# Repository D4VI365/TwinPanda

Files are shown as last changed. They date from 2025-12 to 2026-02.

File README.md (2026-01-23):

# TwinPanda
 Custom Split Wireless Keyboard (nRF52840)
 Un progetto di tastiera meccanica split custom, progettata per essere compatta, ergonomica e completamente wireless grazie alla tecnologia Bluetooth.
 Caratteristiche Principali
 Cervello: Basata su Seeed Studio XIAO nRF52840, ideale per un basso consumo energetico e connettività Bluetooth integrata.
 Espansione I/O: Utilizzo di un chip MCP23017 (SSOP-28) per gestire la matrice dei tasti tramite protocollo $I^2C$.
 Layout Ergonomico: Layout split da 76 tasti ottimizzato per il comfort.
 Case Custom: Progettato in Fusion 360 per essere stampato in 3D con un top frame da 4.5 mm e inserti filettati M3 per la massima solidità.
 Gestione Batteria: Circuito di Battery Sense integrato per il monitoraggio in tempo reale della carica tramite partitore di tensione ($820k\Ohm / 2M\Ohm$).
 
Case:
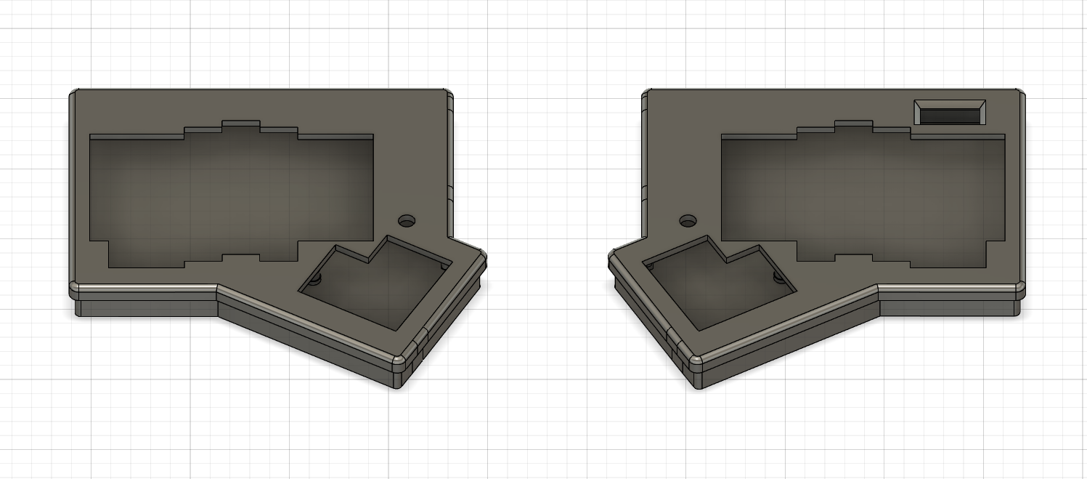
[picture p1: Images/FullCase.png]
FullCase

Full assembly:
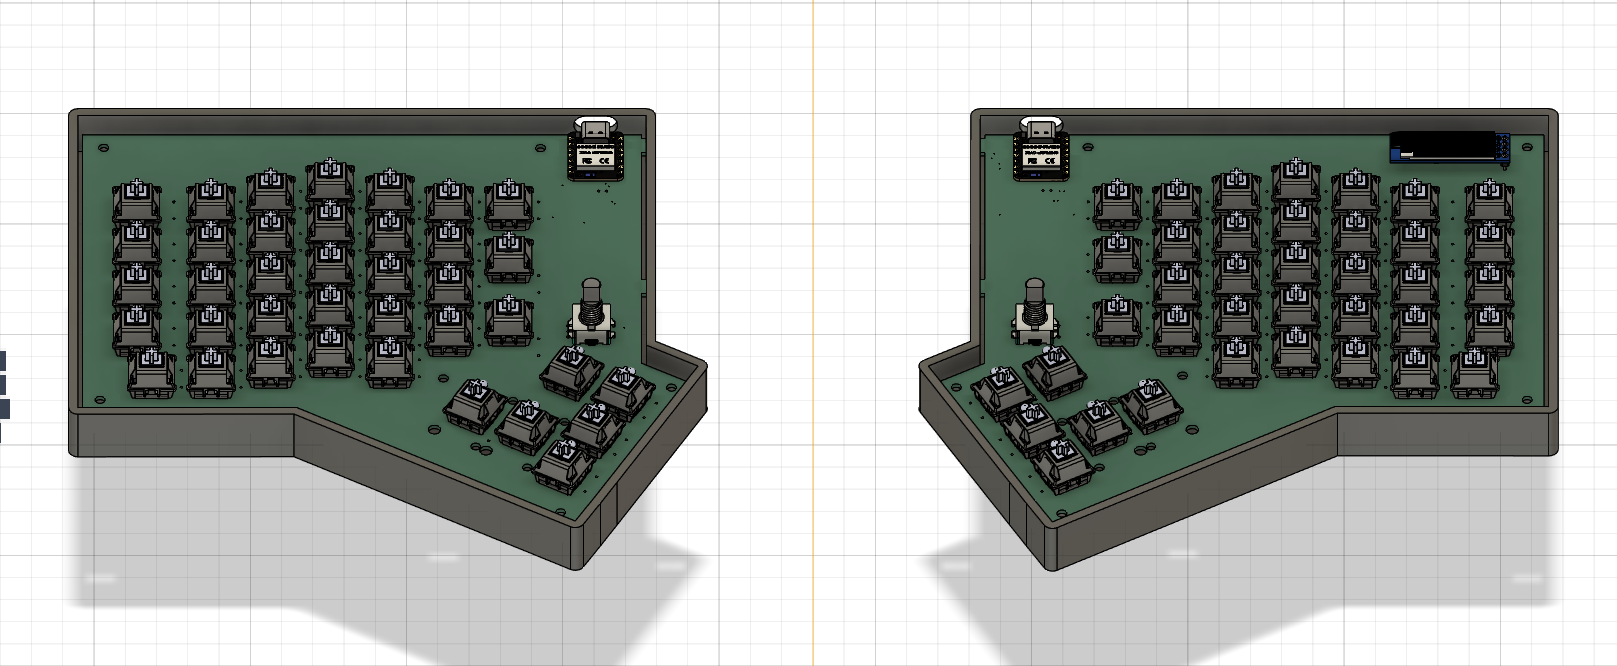
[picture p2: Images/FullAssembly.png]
FullAssembly


PCB Design:
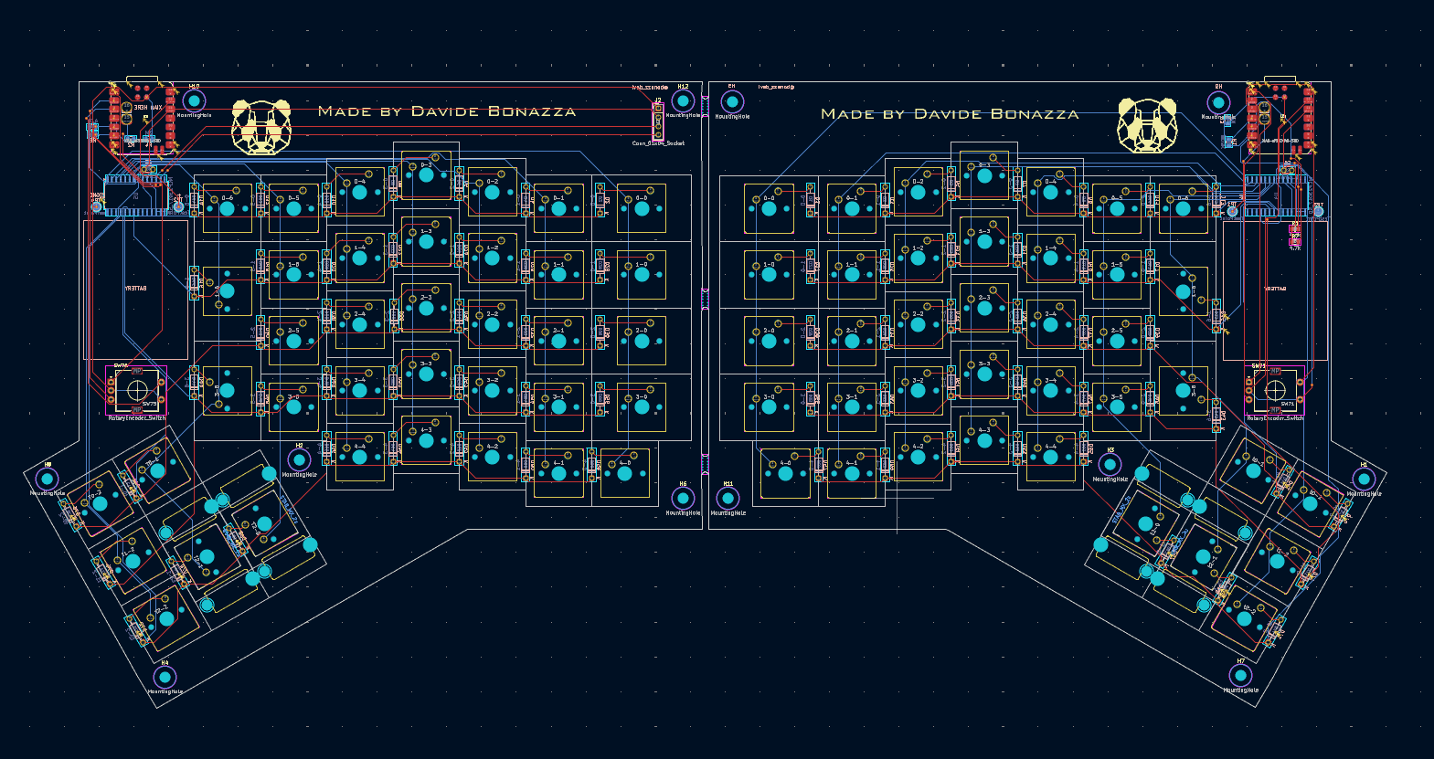
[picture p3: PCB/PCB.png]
PCB


Left Schematic:
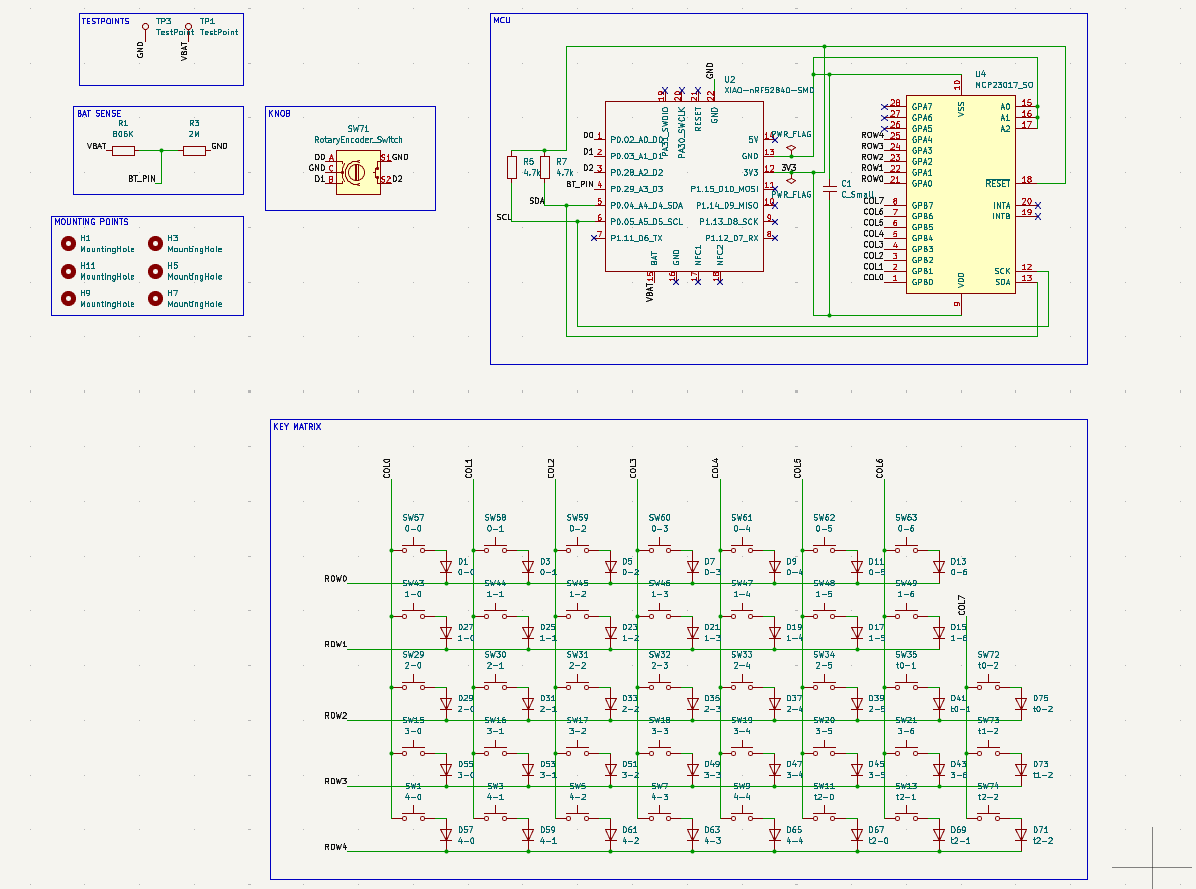
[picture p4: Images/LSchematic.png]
LSchematic


Right Schematic:
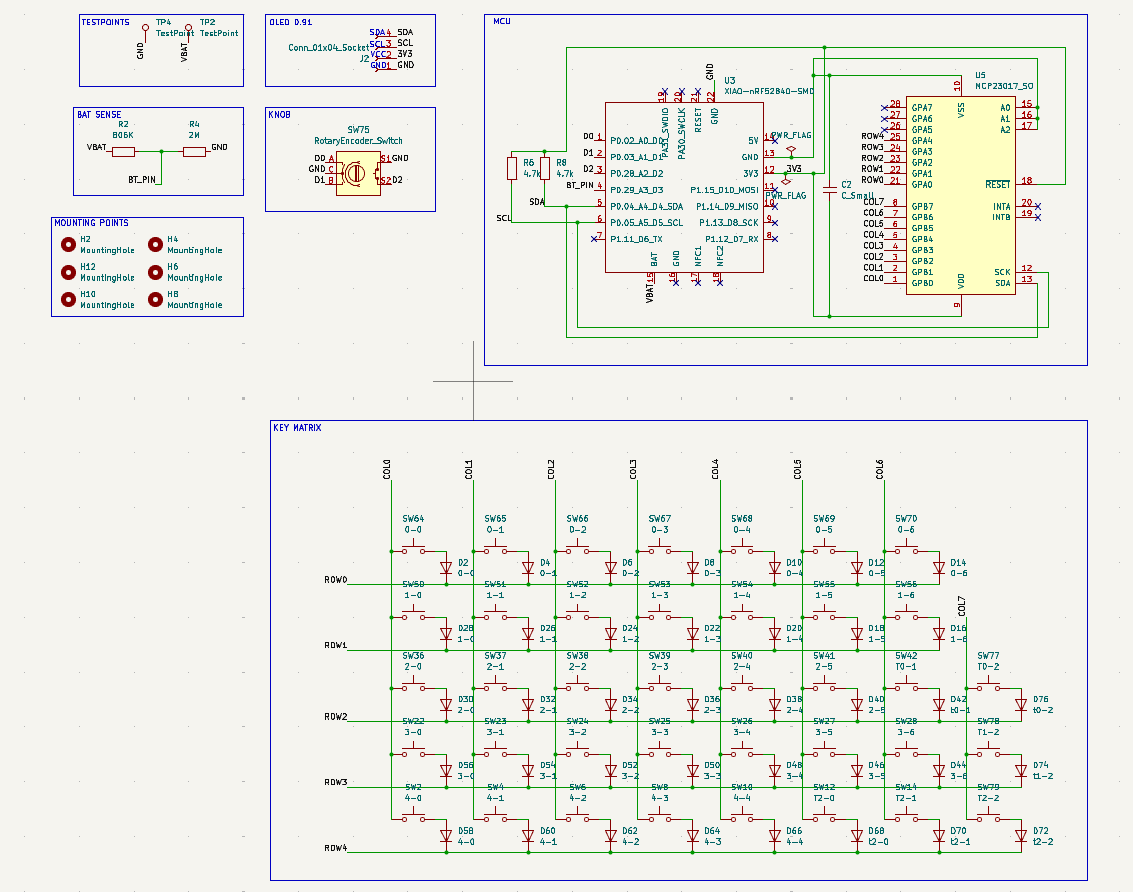
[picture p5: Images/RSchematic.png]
RSchematic


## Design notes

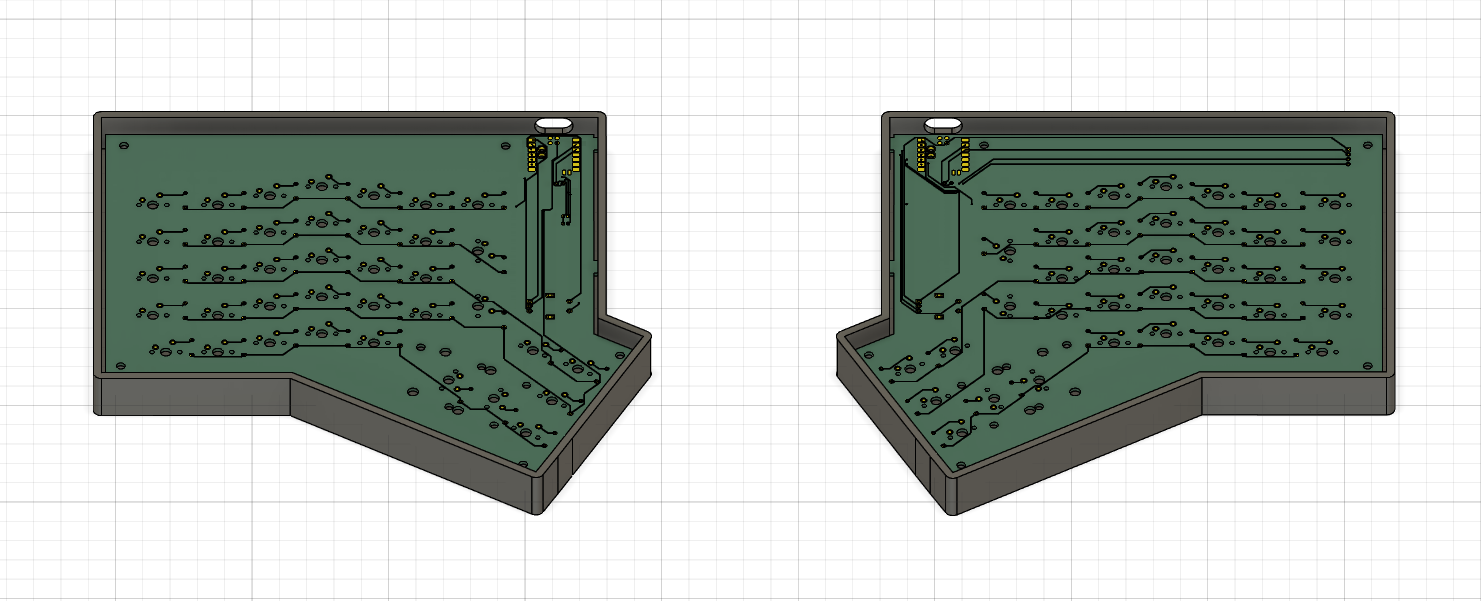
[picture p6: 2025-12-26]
Images/CasePCB.png

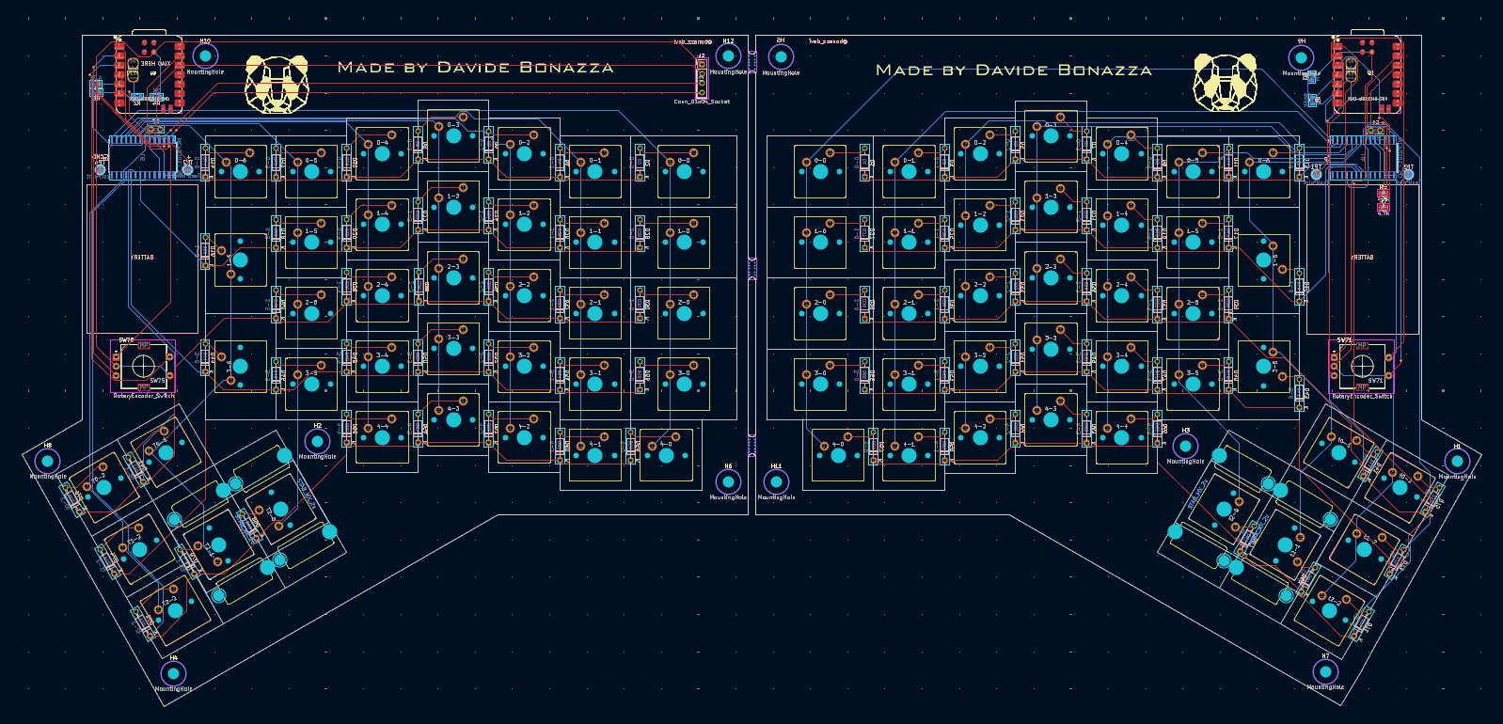
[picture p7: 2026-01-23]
Images/PCB.png

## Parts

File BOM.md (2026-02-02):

## Bill of Materials (BOM)

| Component | Qty | Total Price (USD) | Link | Supplier |
| :--- | :---: | :---: | :--- | :--- |
| **XIAO-nRF52840-SMD** | 2 | 25.03 | [Aliexpress](https://it.aliexpress.com/item/1005006593701624.html) | Aliexpress |
| **MCP23017-SMD** | 2 | 2.40 | [Aliexpress](https://it.aliexpress.com/item/1005004887918583.html) | Aliexpress |
| **Switches (76pcs)** | 76 | 6.50 | [Temu](https://www.temu.com/it-en/g-601105431766700.html) | Temu |
| **Diodes (1N4148)** | 76 | 1.15 | [Temu](https://www.temu.com/it-en/g-601102325033412.html) | Temu |
| **Rotary Encoder** | 2 | 4.20 | [Aliexpress](https://it.aliexpress.com/item/1005006128088045.html) | Aliexpress |
| **4.7Kohm Resistor** | 4 | 2.98 | [Aliexpress](https://it.aliexpress.com/item/1005007129626034.html) | Aliexpress |
| **2Mohm Resistor** | 2 | 3.03 | [Aliexpress](https://it.aliexpress.com/item/1005007129626034.html) | Aliexpress |
| **820Kohm Resistor** | 2 | 3.03 | [Aliexpress](https://it.aliexpress.com/item/1005007129626034.html) | Aliexpress |
| **0.91" OLED Screen** | 1 | 1.81 | [Temu](https://www.temu.com/it-en/g-601100552968759.html) | Temu |
| **2u Key Stabilizer** | 4 | 2.28 | [Temu](https://www.temu.com/it-en/g-606163043249487.html) | Temu |
| **1u Keycaps (60pcs)** | 60 | 17.80 | [Alibaba](https://www.alibaba.com/product-detail/1601240068637.html) | Alibaba |
| **1.5u Keycaps (12pcs)** | 12 | 5.90 | [Alibaba](https://www.alibaba.com/product-detail/1601240068637.html) | Alibaba |
| **2u Keycaps (4pcs)** | 4 | 2.46 | [Alibaba](https://www.alibaba.com/product-detail/1601240068637.html) | Alibaba |
| **M3 Heat-press inserts** | 12 | 1.78 | [Temu](https://www.temu.com/it-en/g-601099714384815.html) | Temu |
| **M3 Screws** | 12 | 1.96 | [Temu](https://www.temu.com/goods.html?goods_id=601101875380737) | Temu |
| **PCB** | 1 | 50.00 | - | JLCPCB |
| **Battery** | 2 | 6.20 | [Aliexpress](https://it.aliexpress.com/item/32856929220.html) | Aliexpress |
| **Capacitor** | 1 | 1.92 | [Aliexpress](https://it.aliexpress.com/item/1005006378388179.html) | Aliexpress |
| --- | --- | --- | --- | --- |
| **TOTAL** | | **140.43** | | |

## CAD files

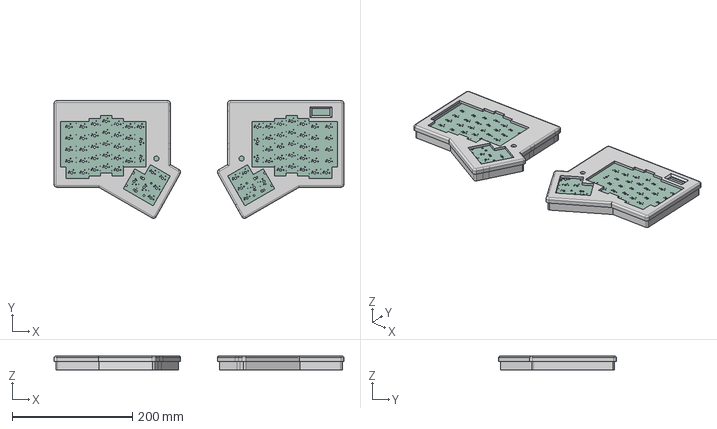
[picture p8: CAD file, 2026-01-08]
CAD/TwinPanda.step
482.5 x 195.9 x 23.5 mm

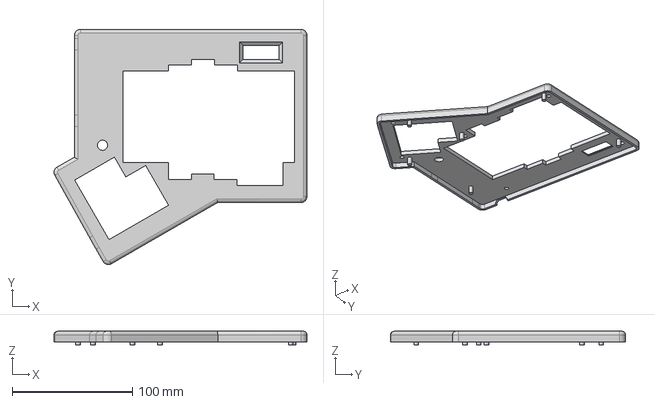
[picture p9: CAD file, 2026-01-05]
CAD/RTopCase.step
210.8 x 195.9 x 11.3 mm

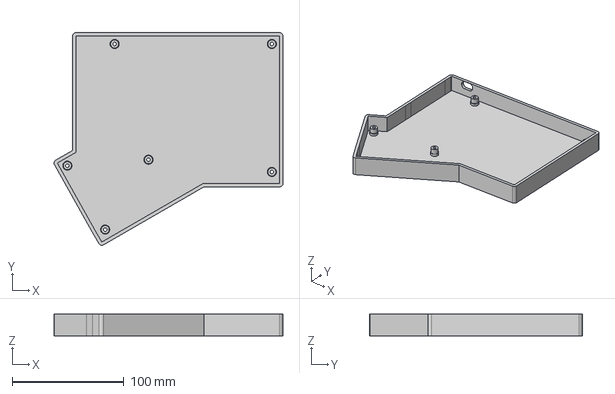
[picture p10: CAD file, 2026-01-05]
CAD/RBottomCase.step
204.5 x 189.9 x 19.3 mm

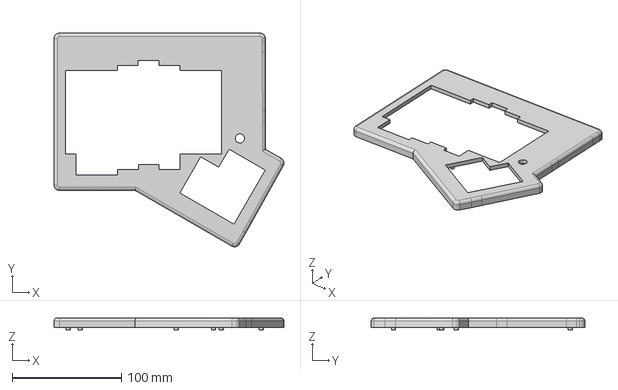
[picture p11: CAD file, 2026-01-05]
CAD/LTopCase.step
210.8 x 195.9 x 11.3 mm

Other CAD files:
CAD/LBottomCase.step
CAD/LBottomCase.stl
CAD/LTopCase.stl
CAD/RBottomCase.stl
CAD/RTopCase.stl
CAD/TwinPanda.f3z

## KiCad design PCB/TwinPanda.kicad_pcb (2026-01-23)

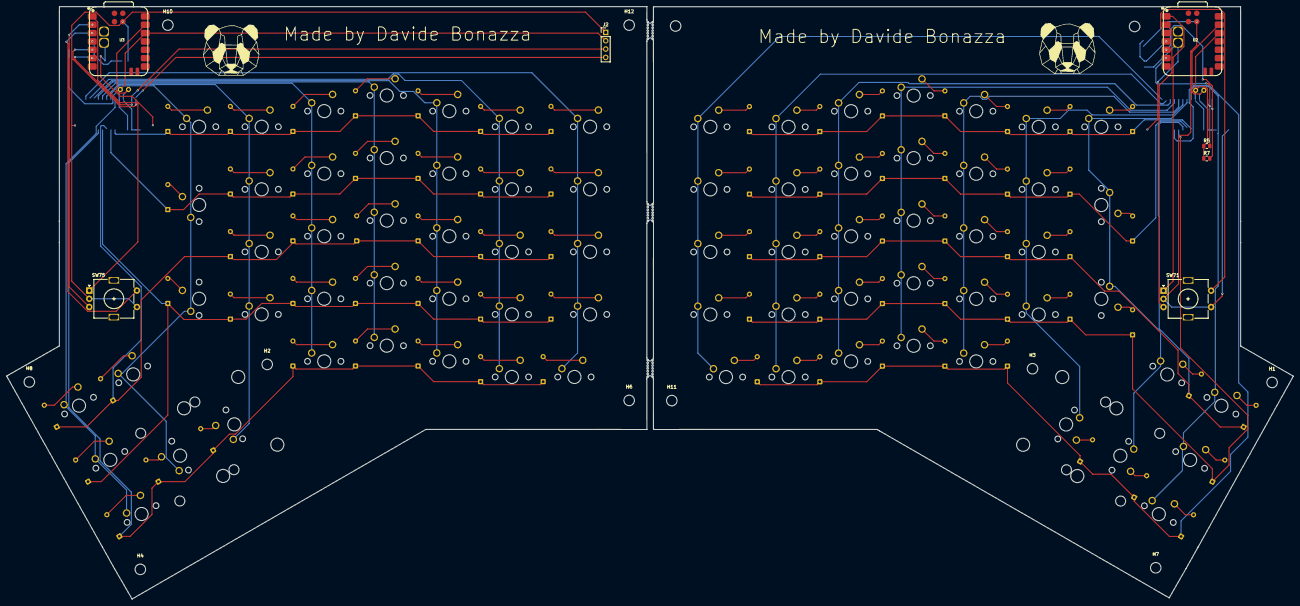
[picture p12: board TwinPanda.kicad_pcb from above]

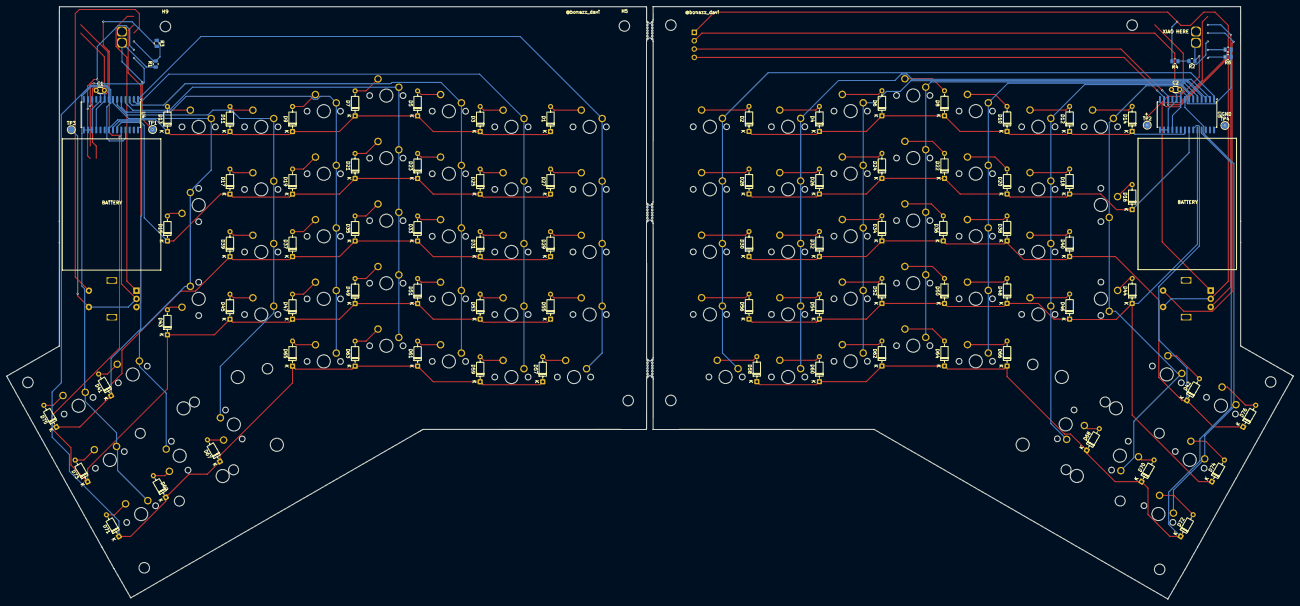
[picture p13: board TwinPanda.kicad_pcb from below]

Board: 2 copper layers, 391.8 x 180.4 mm, 188 parts (90 on the bottom side), 122 nets.

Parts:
BO0, BO1, BO2: MouseBites; MouseBite-Slot_2.0x4.5mm_outset_D0.5mm_P0.85mm_7h
C1, C2: C_Small; C_Disc_D3.0mm_W1.6mm_P2.50mm
D1, D2: 0-0; D_DO-35_SOD27_P7.62mm_Horizontal
D3, D4: 0-1; D_DO-35_SOD27_P7.62mm_Horizontal
D5, D6: 0-2; D_DO-35_SOD27_P7.62mm_Horizontal
D7, D8: 0-3; D_DO-35_SOD27_P7.62mm_Horizontal
D9, D10: 0-4; D_DO-35_SOD27_P7.62mm_Horizontal
D11, D12: 0-5; D_DO-35_SOD27_P7.62mm_Horizontal
D13, D14: 0-6; D_DO-35_SOD27_P7.62mm_Horizontal
D15, D16: 1-6; D_DO-35_SOD27_P7.62mm_Horizontal
D17, D18: 1-5; D_DO-35_SOD27_P7.62mm_Horizontal
D19, D20: 1-4; D_DO-35_SOD27_P7.62mm_Horizontal
D21, D22: 1-3; D_DO-35_SOD27_P7.62mm_Horizontal
D23, D24: 1-2; D_DO-35_SOD27_P7.62mm_Horizontal
D25, D26: 1-1; D_DO-35_SOD27_P7.62mm_Horizontal
D27, D28: 1-0; D_DO-35_SOD27_P7.62mm_Horizontal
D29, D30: 2-0; D_DO-35_SOD27_P7.62mm_Horizontal
D31, D32: 2-1; D_DO-35_SOD27_P7.62mm_Horizontal
D33, D34: 2-2; D_DO-35_SOD27_P7.62mm_Horizontal
D35, D36: 2-3; D_DO-35_SOD27_P7.62mm_Horizontal
D37, D38: 2-4; D_DO-35_SOD27_P7.62mm_Horizontal
D39, D40: 2-5; D_DO-35_SOD27_P7.62mm_Horizontal
D41, D42: t0-1; D_DO-35_SOD27_P7.62mm_Horizontal
D43, D44: 3-6; D_DO-35_SOD27_P7.62mm_Horizontal
D45, D46: 3-5; D_DO-35_SOD27_P7.62mm_Horizontal
D47, D48: 3-4; D_DO-35_SOD27_P7.62mm_Horizontal
D49, D50: 3-3; D_DO-35_SOD27_P7.62mm_Horizontal
D51, D52: 3-2; D_DO-35_SOD27_P7.62mm_Horizontal
D53, D54: 3-1; D_DO-35_SOD27_P7.62mm_Horizontal
D55, D56: 3-0; D_DO-35_SOD27_P7.62mm_Horizontal
D57, D58: 4-0; D_DO-35_SOD27_P7.62mm_Horizontal
D59, D60: 4-1; D_DO-35_SOD27_P7.62mm_Horizontal
D61, D62: 4-2; D_DO-35_SOD27_P7.62mm_Horizontal
D63, D64: 4-3; D_DO-35_SOD27_P7.62mm_Horizontal
D65, D66: 4-4; D_DO-35_SOD27_P7.62mm_Horizontal
D67, D68: t2-0; D_DO-35_SOD27_P7.62mm_Horizontal
D69, D70: t2-1; D_DO-35_SOD27_P7.62mm_Horizontal
D71, D72: t2-2; D_DO-35_SOD27_P7.62mm_Horizontal
D73, D74: t1-2; D_DO-35_SOD27_P7.62mm_Horizontal
D75, D76: t0-2; D_DO-35_SOD27_P7.62mm_Horizontal
H1, H2, H3, H4, H5, H6, H7, H8, H9, H10, H11, H12: MountingHole; MountingHole_3.2mm_M3
J2: Conn_01x04_Socket; PinHeader_1x04_P2.54mm_Vertical
R1, R2: 806K; R_0805_2012Metric
R3, R4: 2M; R_0805_2012Metric
R5, R6, R7, R8: 4.7k; R_0805_2012Metric
SW1, SW2: 4-0; SW_MX_1u
SW3, SW4: 4-1; SW_MX_1u
SW5, SW6: 4-2; SW_MX_1u
SW7, SW8: 4-3; SW_MX_1u
SW9, SW10: 4-4; SW_MX_1u
SW11: t2-0; SW_MX_1u
SW12: T2-0; SW_MX_1u
SW13: t2-1; SW_MX_1u
SW14: T2-1; SW_MX_1u
SW15, SW22: 3-0; SW_MX_1.5u
SW16, SW23: 3-1; SW_MX_1u
SW17, SW24: 3-2; SW_MX_1u
SW18, SW25: 3-3; SW_MX_1u
SW19, SW26: 3-4; SW_MX_1u
SW20, SW27: 3-5; SW_MX_1u
SW21, SW28: 3-6; SW_MX_1.5u
SW29, SW36: 2-0; SW_MX_1.5u
SW30, SW37: 2-1; SW_MX_1u
SW31, SW38: 2-2; SW_MX_1u
SW32, SW39: 2-3; SW_MX_1u
SW33, SW40: 2-4; SW_MX_1u
SW34, SW41: 2-5; SW_MX_1u
SW35: t0-1; SW_MX_1u
SW42: T0-1; SW_MX_1u
SW43, SW50: 1-0; SW_MX_1.5u
SW44, SW51: 1-1; SW_MX_1u
SW45, SW52: 1-2; SW_MX_1u
SW46, SW53: 1-3; SW_MX_1u
SW47, SW54: 1-4; SW_MX_1u
SW48, SW55: 1-5; SW_MX_1u
SW49, SW56: 1-6; SW_MX_1.5u
SW57, SW64: 0-0; SW_MX_1.5u
SW58, SW65: 0-1; SW_MX_1u
SW59, SW66: 0-2; SW_MX_1u
SW60, SW67: 0-3; SW_MX_1u
SW61, SW68: 0-4; SW_MX_1u
SW62, SW69: 0-5; SW_MX_1u
SW63, SW70: 0-6; SW_MX_1u
SW71, SW75: RotaryEncoder_Switch; RotaryEncoder_Alps_EC11E-Switch_Vertical_H20mm
SW72: t0-2; SW_MX_1u
SW73: t1-2; SW_MX_1u
SW74: t2-2; SW_MX_1u
SW77: T0-2; SW_MX_1u
SW78: T1-2; SW_MX_1u
SW79: T2-2; SW_MX_1u
TP1, TP2, TP3, TP4: TestPoint; TestPoint_Pad_D2.0mm
U2, U3: XIAO-nRF52840-SMD; modified-XIAO-nRF52840-SMD
U4, U5: MCP23017_SO; SOIC-28W_7.5x17.9mm_P1.27mm

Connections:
/Left/3V3: C1.2, R5.1, R7.1, U2.12 (3V3), U4.9 (VDD), U4.18 (~RESET)
/Left/BT_PIN: R1.2, R3.1, U2.4 (P0.29_A3_D3)
/Left/COL0: SW1.1, SW15.1, SW29.1, SW43.1, SW57.1, U4.1 (GPB0)
/Left/COL1: SW3.1, SW16.1, SW30.1, SW44.1, SW58.1, U4.2 (GPB1)
/Left/COL2: SW5.1, SW17.1, SW31.1, SW45.1, SW59.1, U4.3 (GPB2)
/Left/COL3: SW7.1, SW18.1, SW32.1, SW46.1, SW60.1, U4.4 (GPB3)
/Left/COL4: SW9.1, SW19.1, SW33.1, SW47.1, SW61.1, U4.5 (GPB4)
/Left/COL5: SW11.1, SW20.1, SW34.1, SW48.1, SW62.1, U4.6 (GPB5)
/Left/COL6: SW13.1, SW21.1, SW35.1, SW49.1, SW63.1, U4.7 (GPB6)
/Left/COL7: SW72.1, SW73.1, SW74.1, U4.8 (GPB7)
/Left/D0: SW71.A, U2.1 (P0.02_A0_D0)
/Left/D1: SW71.B, U2.2 (P0.03_A1_D1)
/Left/D2: SW71.S2, U2.3 (P0.28_A2_D2)
/Left/GND: R3.2, SW71.C, SW71.S1, TP3.1, U2.22 (GND)
/Left/ROW0: D1.1 (K), D3.1 (K), D5.1 (K), D7.1 (K), D9.1 (K), D11.1 (K), D13.1 (K), U4.21 (GPA0)
/Left/ROW1: D15.1 (K), D17.1 (K), D19.1 (K), D21.1 (K), D23.1 (K), D25.1 (K), D27.1 (K), U4.22 (GPA1)
/Left/ROW2: D29.1 (K), D31.1 (K), D33.1 (K), D35.1 (K), D37.1 (K), D39.1 (K), D41.1 (K), D75.1 (K), U4.23 (GPA2)
/Left/ROW3: D43.1 (K), D45.1 (K), D47.1 (K), D49.1 (K), D51.1 (K), D53.1 (K), D55.1 (K), D73.1 (K), U4.24 (GPA3)
/Left/ROW4: D57.1 (K), D59.1 (K), D61.1 (K), D63.1 (K), D65.1 (K), D67.1 (K), D69.1 (K), D71.1 (K), U4.25 (GPA4)
/Left/SCL: R5.2, U2.6 (P0.05_A5_D5_SCL), U4.12 (SCK)
/Left/SDA: R7.2, U2.5 (P0.04_A4_D4_SDA), U4.13 (SDA)
/Left/VBAT: R1.1, TP1.1, U2.15 (BAT)
/Right/3V3: C2.2, J2.2, R6.1, R8.1, U3.12 (3V3), U5.9 (VDD), U5.18 (~RESET)
/Right/BT_PIN: R2.2, R4.1, U3.4 (P0.29_A3_D3)
/Right/COL0: SW2.1, SW22.1, SW36.1, SW50.1, SW64.1, U5.1 (GPB0)
/Right/COL1: SW4.1, SW23.1, SW37.1, SW51.1, SW65.1, U5.2 (GPB1)
/Right/COL2: SW6.1, SW24.1, SW38.1, SW52.1, SW66.1, U5.3 (GPB2)
/Right/COL3: SW8.1, SW25.1, SW39.1, SW53.1, SW67.1, U5.4 (GPB3)
/Right/COL4: SW10.1, SW26.1, SW40.1, SW54.1, SW68.1, U5.5 (GPB4)
/Right/COL5: SW12.1, SW27.1, SW41.1, SW55.1, SW69.1, U5.6 (GPB5)
/Right/COL6: SW14.1, SW28.1, SW42.1, SW56.1, SW70.1, U5.7 (GPB6)
/Right/COL7: SW77.1, SW78.1, SW79.1, U5.8 (GPB7)
/Right/D0: SW75.A, U3.1 (P0.02_A0_D0)
/Right/D1: SW75.B, U3.2 (P0.03_A1_D1)
/Right/D2: SW75.S2, U3.3 (P0.28_A2_D2)
/Right/GND: J2.1, R4.2, SW75.C, SW75.S1, TP4.1, U3.22 (GND)
/Right/ROW0: D2.1 (K), D4.1 (K), D6.1 (K), D8.1 (K), D10.1 (K), D12.1 (K), D14.1 (K), U5.21 (GPA0)
/Right/ROW1: D16.1 (K), D18.1 (K), D20.1 (K), D22.1 (K), D24.1 (K), D26.1 (K), D28.1 (K), U5.22 (GPA1)
/Right/ROW2: D30.1 (K), D32.1 (K), D34.1 (K), D36.1 (K), D38.1 (K), D40.1 (K), D42.1 (K), D76.1 (K), U5.23 (GPA2)
/Right/ROW3: D44.1 (K), D46.1 (K), D48.1 (K), D50.1 (K), D52.1 (K), D54.1 (K), D56.1 (K), D74.1 (K), U5.24 (GPA3)
/Right/ROW4: D58.1 (K), D60.1 (K), D62.1 (K), D64.1 (K), D66.1 (K), D68.1 (K), D70.1 (K), D72.1 (K), U5.25 (GPA4)
/Right/SCL: J2.3, R6.2, U3.6 (P0.05_A5_D5_SCL), U5.12 (SCK)
/Right/SDA: J2.4, R8.2, U3.5 (P0.04_A4_D4_SDA), U5.13 (SDA)
/Right/VBAT: R2.1, TP2.1, U3.15 (BAT)
unnamed: D1.2 (A), SW57.2
unnamed: D2.2 (A), SW64.2
unnamed: D3.2 (A), SW58.2
unnamed: D4.2 (A), SW65.2
unnamed: D5.2 (A), SW59.2
unnamed: D6.2 (A), SW66.2
unnamed: D7.2 (A), SW60.2
unnamed: D8.2 (A), SW67.2
unnamed: D9.2 (A), SW61.2
unnamed: D10.2 (A), SW68.2
unnamed: D11.2 (A), SW62.2
unnamed: D12.2 (A), SW69.2
unnamed: D13.2 (A), SW63.2
unnamed: D14.2 (A), SW70.2
unnamed: D15.2 (A), SW49.2
unnamed: D16.2 (A), SW56.2
unnamed: D17.2 (A), SW48.2
unnamed: D18.2 (A), SW55.2
unnamed: D19.2 (A), SW47.2
unnamed: D20.2 (A), SW54.2
unnamed: D21.2 (A), SW46.2
unnamed: D22.2 (A), SW53.2
unnamed: D23.2 (A), SW45.2
unnamed: D24.2 (A), SW52.2
unnamed: D25.2 (A), SW44.2
unnamed: D26.2 (A), SW51.2
unnamed: D27.2 (A), SW43.2
unnamed: D28.2 (A), SW50.2
unnamed: D29.2 (A), SW29.2
unnamed: D30.2 (A), SW36.2
unnamed: D31.2 (A), SW30.2
unnamed: D32.2 (A), SW37.2
unnamed: D33.2 (A), SW31.2
unnamed: D34.2 (A), SW38.2
unnamed: D35.2 (A), SW32.2
unnamed: D36.2 (A), SW39.2
unnamed: D37.2 (A), SW33.2
unnamed: D38.2 (A), SW40.2
unnamed: D39.2 (A), SW34.2
unnamed: D40.2 (A), SW41.2
unnamed: D41.2 (A), SW35.2
unnamed: D42.2 (A), SW42.2
unnamed: D43.2 (A), SW21.2
unnamed: D44.2 (A), SW28.2
unnamed: D45.2 (A), SW20.2
unnamed: D46.2 (A), SW27.2
unnamed: D47.2 (A), SW19.2
unnamed: D48.2 (A), SW26.2
unnamed: D49.2 (A), SW18.2
unnamed: D50.2 (A), SW25.2
unnamed: D51.2 (A), SW17.2
unnamed: D52.2 (A), SW24.2
unnamed: D53.2 (A), SW16.2
unnamed: D54.2 (A), SW23.2
unnamed: D55.2 (A), SW15.2
unnamed: D56.2 (A), SW22.2
unnamed: D57.2 (A), SW1.2
unnamed: D58.2 (A), SW2.2
unnamed: D59.2 (A), SW3.2
unnamed: D60.2 (A), SW4.2
unnamed: D61.2 (A), SW5.2
unnamed: D62.2 (A), SW6.2
unnamed: D63.2 (A), SW7.2
unnamed: D64.2 (A), SW8.2
unnamed: D65.2 (A), SW9.2
unnamed: D66.2 (A), SW10.2
unnamed: D67.2 (A), SW11.2
unnamed: D68.2 (A), SW12.2
unnamed: D69.2 (A), SW13.2
unnamed: D70.2 (A), SW14.2
unnamed: D71.2 (A), SW74.2
unnamed: D72.2 (A), SW79.2
unnamed: D73.2 (A), SW73.2
unnamed: D74.2 (A), SW78.2
unnamed: D75.2 (A), SW72.2
unnamed: D76.2 (A), SW77.2
unnamed: C1.1, U2.13 (GND), U4.10 (VSS), U4.15 (A0), U4.16 (A1), U4.17 (A2)
unnamed: C2.1, U3.13 (GND), U5.10 (VSS), U5.15 (A0), U5.16 (A1), U5.17 (A2)

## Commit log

2025-12-26 Added the files
    [BOM.csv]
2026-01-20 Add assembly and PCB schematic images
    Added FullAssembly.png to Images and LSchematic.png, RSchematic.png, and PCB.png to PCB directory for documentation and reference purposes.
2026-01-23 Update BOM, PCB layout, and assembly images
    Updated BOM.csv with new suppliers, lower prices, and alternative links for several components. Modified the PCB layout (TwinPanda.kicad_pcb) with significant changes to component and mounting hole p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
    [BOM.csv, TwinPanda.kicad_pcb]
2026-01-31 Update BOM with new prices, suppliers, and links
    Updated the Bill of Materials to reflect new prices, suppliers, and product links for multiple components. Some quantities and sources have changed, and total price has been recalculated. Added empty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
    [BOM.csv]
2026-01-31 Update BOM component prices
    Adjusted prices for several components in BOM.csv, including Switches, Diodes, Rotary Encoder, OLED screen, key stabilizer, M3 Heat-press insert, and M3 Screws. Updated the total price to reflect the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
    [BOM.csv]
2026-02-02 Update BOM currency label to USD
    Changed the 'Total price' column header in BOM.csv from an invalid character to 'Total price USD' for clarity.
    [BOM.csv]
2026-02-02 Simplify and update BOM component links
    Shortened and standardized URLs for several components in BOM.csv to remove tracking parameters and improve readability. Also updated the total price row and made minor formatting adjustments.
    [BOM.csv]
2026-02-02 Remove BOM.csv and move build.yaml to Firmware/
    Deleted the BOM.csv file and relocated build.yaml to the Firmware directory. This cleans up the project structure and organizes build configuration files.
    [BOM.csv]
2026-02-16 Add TwinPanda.f3z CAD model
    Add a new Fusion 360 archive (TwinPanda.f3z) to the CAD directory. This commits the initial binary CAD design source for the TwinPanda project.
    [TwinPanda.f3z]
